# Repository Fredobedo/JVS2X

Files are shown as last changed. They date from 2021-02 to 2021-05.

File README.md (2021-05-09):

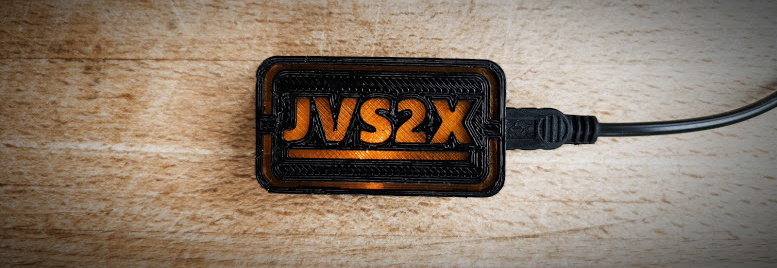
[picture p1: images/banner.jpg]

 <h2>Introduction </h2>
 I was not really in favor of integrating Gaming consoles in arcade CABs but I gave a try with a Sony Playstation 3 and could confirm that:
 <BR>&nbsp&nbsp&nbsp-&nbspIt can natively output 640x480@60Hz with 4:3 aspect ratio (not all games)
 <BR>&nbsp&nbsp&nbsp-&nbspIt natively supports Logitech G25 racing Wheel with full FFB and has some excellent arcade ports (i.e. OutRun 2 SP, Sega Rally, GTI Club)
 <BR>&nbsp&nbsp&nbsp-&nbspIt can run arcade Shoot'em ups (i.e. RayStorm HD) and Beat'em ups (i.e. Street Fighter IV Arcade Edition)
 <BR>&nbsp&nbsp&nbsp-&nbspIt could be an excellent solution for rail shooting games with also very interesting arcade ports
 <BR>
 <BR>For the racing games, it was not a problem as I could directly connect my racing wheel but I needed an interface for being able to play other games with my CAB's controller. 
 <BR> -> I decided to use a Teensy 2.0 for this purpose as already done by other users but with small changes to fit my needs. 
 <BR> 
 <BR>JVS2X (Teensy) acts as an interface between the Game console/PC and the Arcade JVS IO Board, converting JVS protocol to USB (software HID Device). 
 <BR>When compiled in JVS2PS3 mode, the Teensy will represents a USB composite Device exposes 2 HID interfaces of type gamepad controllers.
 <BR>When compiled in JVS2KEYBOARD mode, the Teensy will represents a USB composite Device exposes 2 HID interfaces of type Keyboard. 
 <BR>
 <BR>Here is a non exhaustive list of systems that should be compatible today when compiled in JVS2PS3 mode (TBC):
 <BR>&nbsp&nbsp&nbsp-&nbspSony Playstation 3 (Home button supported: 'Start + Button 1')
 <BR>&nbsp&nbsp&nbsp-&nbspMicrosoft Windows (i.e. Mame)
 <BR>&nbsp&nbsp&nbsp-&nbspLinux based systems (i.e. RetroPie)
 <BR>&nbsp&nbsp&nbsp-&nbspNintendo Switch 
 <BR>&nbsp&nbsp&nbsp-&nbspEtc.
 <BR>
 <BR>This project is not something new; it is highly inspired from other projects referenced at the bottom of this page.
 <BR>Do not hesitate to look at these projects to have more information.
 <BR>
 <BR>What could be considered as new here, is the way it is implemented (technical aspects):
 <BR>&nbsp&nbsp&nbsp-&nbspBulk JVS Commands dynamically built based on supported JVS client features
 <BR>&nbsp&nbsp&nbsp-&nbspAnalog and LightGun support
 <BR>&nbsp&nbsp&nbsp-&nbspDaisy chain support
 <BR>&nbsp&nbsp&nbsp-&nbspConfigurable multi CABs
 <BR>&nbsp&nbsp&nbsp-&nbspOptimized USB report updates
 <BR>&nbsp&nbsp&nbsp-&nbspBasic Analog Fuzz filters
 <BR>&nbsp&nbsp&nbsp-&nbspController remapping facilities
 <BR>&nbsp&nbsp&nbsp-&nbsp2 keyboards interfaces to circumvent limitation of 8 keystrokes (6 non-modifier keycodes + 2 modifiers) per Keyboard report (=> 2x 6KRO).
 <BR>&nbsp&nbsp&nbsp-&nbspSupport multi Keyboard layout
 <BR>&nbsp&nbsp&nbsp-&nbspSupport for programmable shiftKeys
 <BR>&nbsp&nbsp&nbsp-&nbspEtc. 
 <BR> 
 <BR>Here is a video of a PS3 in an arcade CAB with Logitech G25 Racing Wheel (FFB full support natively) :
 <BR><a href="http://www.youtube.com/watch?feature=player_embedded&v=FEGdqCKUjls
" target="_blank">IMAGE ALT TEXT HERE</a>
  
 <BR>Here is another video of a PS3 in an arcade CAB but this time with a JVS2X adapter connected to JVS IO Board (for 'sticks' games) :
 <BR><a href="http://www.youtube.com/watch?feature=player_embedded&v=nGHq-c_uzvw
" target="_blank">IMAGE ALT TEXT HERE</a>
  
 <BR>
  
 <BR>TODO: Implement HID for PS4, XBOX One, etc. when I have time or with your help :) 
 
<h2>Supported arcade layout</h2>
JVS2X is developed to support device chaining, thus it supports multiple JVS IO boards in the same CAB or in different CABs (Clone mode, VS mode, etc.)
<BR>All is implemented but I can't test as I do only have 1 CAB :( 
<BR>If someone is willing to give it a try, I will be more than happy to help in case of trouble
<BR>
<BR>You can configure your CAB's layout by updating file jvs_host_config.h:
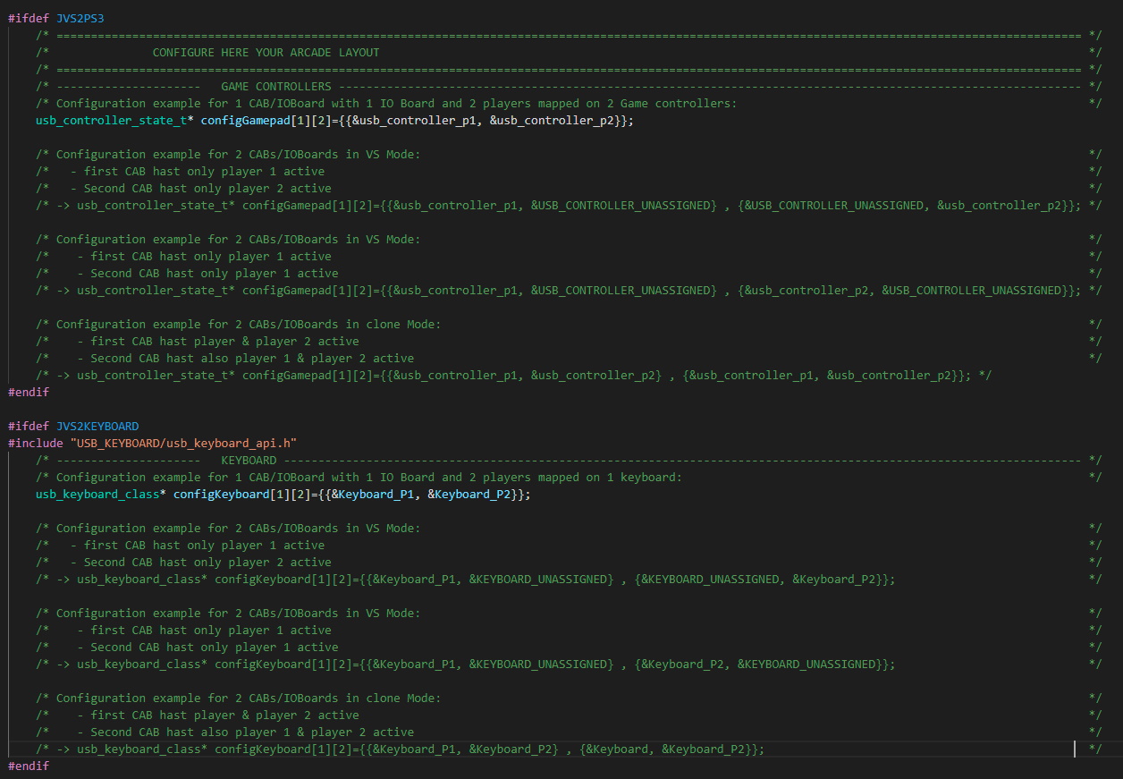
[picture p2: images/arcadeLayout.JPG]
<BR> 

<h2>Building the hardware</h2>
Here are the components you need to construct your adapter (total max. 15€):
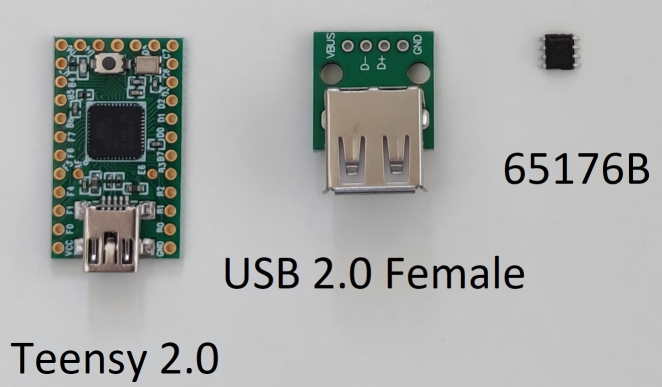
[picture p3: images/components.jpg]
   

<BR>Then, you have the possibility to buy a pcb helper for a very reasonable from Aganyte (easy way):
<table>
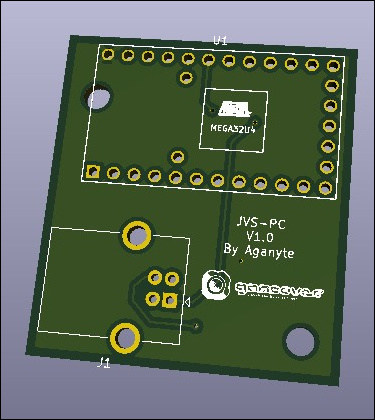
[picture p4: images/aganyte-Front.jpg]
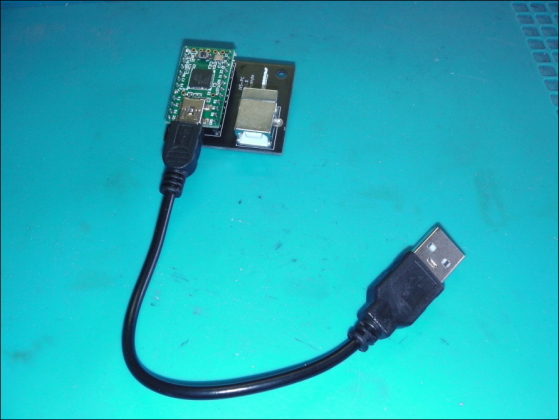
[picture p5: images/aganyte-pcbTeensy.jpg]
<td></td><td></td>
</table>
more information at https://www.gamoover.net/Forums/index.php?topic=43288.0

<BR>And for the courageous one, here is diagram for soldering all yourself without the Aganyte's PCB (hardcore way):
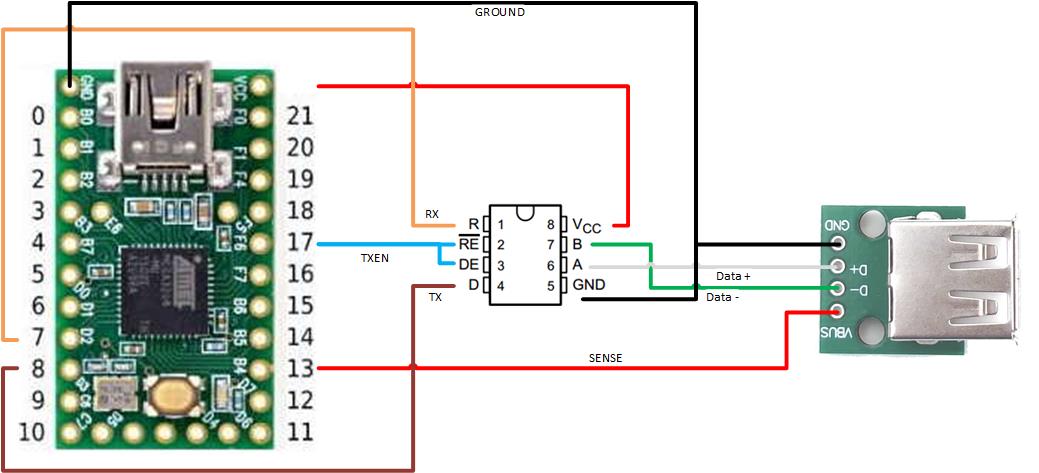
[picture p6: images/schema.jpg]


This is the way I soldered mine (c/o compatible enclosure below if needed):
<table>
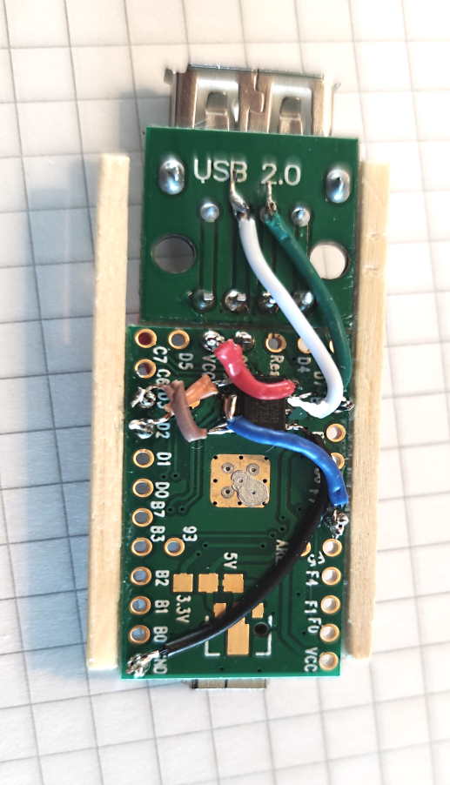
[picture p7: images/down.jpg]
<td></td>
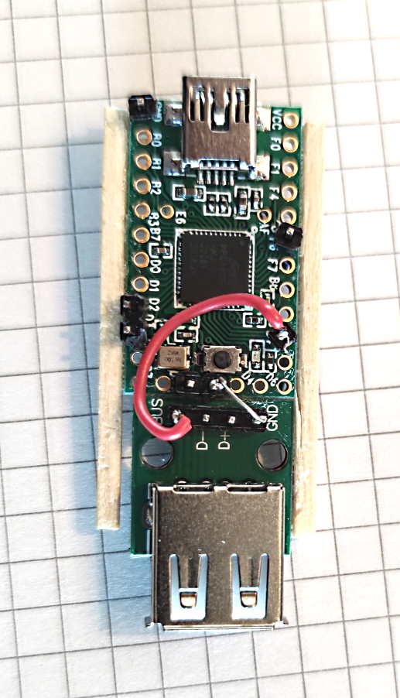
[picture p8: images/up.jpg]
<td></td>
</table>
There are also additional pictures from other realizations for other persons, in the doc folder if needed.

<h2>Printing an enclosure</h2>
I also designed a box for the JVS2X:
<table>
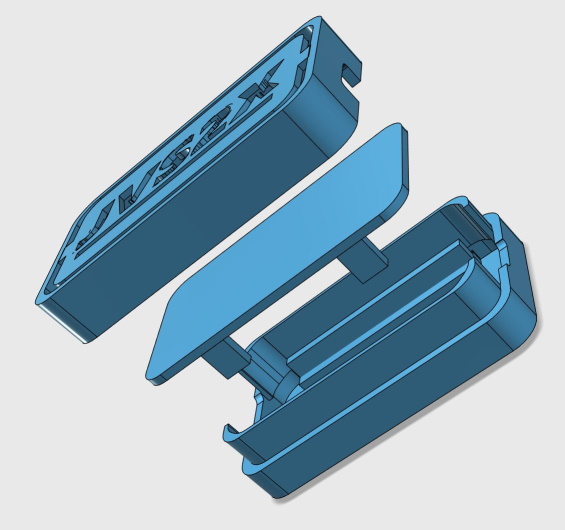
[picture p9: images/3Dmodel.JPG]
<tr><td colspan="2"></td></tr>
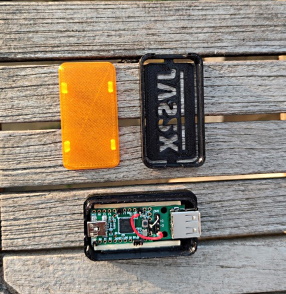
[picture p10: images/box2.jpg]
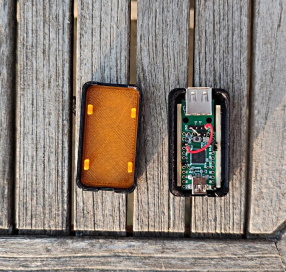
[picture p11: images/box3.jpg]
<tr><td></td><td></td></tr>
</table>
In case you are interested, You can find the 3 STL files in the 'Enclosure' folder.

<h2>Compiling the software</h2>
 For now on, I use VS Code with PlatformIO IDE extension:
 <BR>&nbsp&nbsp&nbsp-&nbspBoard: Teensy 2.0
 <BR>&nbsp&nbsp&nbsp-&nbspFramework: Arduino
 <BR>Here are the supported build flags (c/o platformio.ini):
  <table>
 <TD>&nbsp&nbsp&nbsp-&nbspJVS2PS3</td><td> -> create 2 gamepad controllers compatible with ps3, pc, etc.</td><tr>
 <TD>&nbsp&nbsp&nbsp-&nbspJVS2KEYBOARD</td><td> -> create 2 keyboards</td><tr>
 <TD>&nbsp&nbsp&nbsp-&nbspJVSDEBUG=1</td><td> -> activate info traces</td><tr>
 <TD>&nbsp&nbsp&nbsp-&nbspJVSDEBUG=2</td><td> -> activate debug traces</td><tr>
 <TD>&nbsp&nbsp&nbsp-&nbspLAYOUT_FRENCH_BELGIAN</td><td> -> set keyboard layout to French for Unicode keyboard mapping</td><tr>
 <TD>&nbsp&nbsp&nbsp-&nbspSENSE_DISABLED</td><td> -> disable sense line</td><tr>
 <TD>&nbsp&nbsp&nbsp-&nbspSHIFTKEY_DISABLED</td><td> -> disable keyboard shift keys support</td><tr>
  </table>
 <BR>If you don't want to compile it, there is already a compiled version in 'build' folder
  
 <h2>Upload software</h2>
 Please upload 'jvs2x.hex' in your Teensy with help of Teensy Loader (c/o pjrc.com).
 <BR>
 
 <h2>Debugging</h2>
You can compile JVS2X with JVSDEBUG flag; this will create a additional HID interface that you will connect with help of hid_listen.exe (c/o https://www.pjrc.com/teensy/hid_listen.html for more information)
<BR>
<BR>You should see these traces:
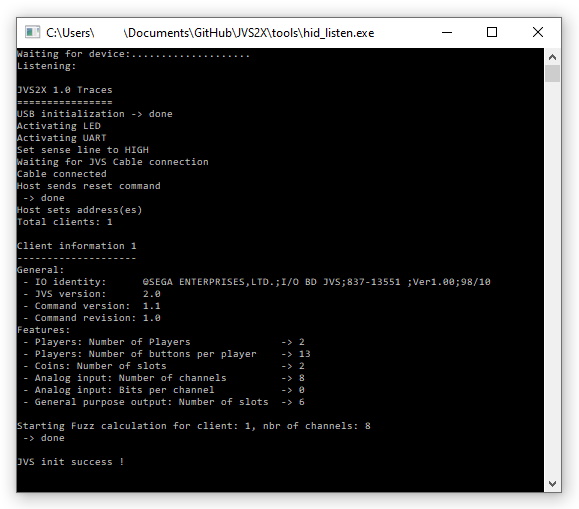
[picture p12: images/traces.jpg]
<BR>
<BR>If you do not want to compile it, I also have placed debug versions in 'build' folder too.

 <h2>LED States</h2>
JVS2X uses the Teensy internal LED to indicate several states:
<BR>&nbsp&nbsp&nbsp-&nbspContinuously blinking: waiting for a JVS cable to be connected
<BR>&nbsp&nbsp&nbsp-&nbspNo blink: init phase started
<BR>&nbsp&nbsp&nbsp-&nbspSteady ON: JVS init is finished successfully and the device is ready

<h2>Compatibilty list</h2>
Here are some games confirmed to work on Sony PlayStation 3:
<BR>&nbsp&nbspWorking:
<BR>&nbsp&nbsp&nbsp-&nbspUnder defeat HD
<BR>&nbsp&nbsp&nbsp-&nbspRayStorm HD
<BR>&nbsp&nbsp&nbsp-&nbspSuper Street Fighter IV Arcade Edition
<BR>&nbsp&nbsp&nbsp-&nbspVirtua Fighter 5 
<BR>&nbsp&nbsp&nbsp-&nbspSöldner-X 2
<BR>&nbsp&nbsp&nbsp-&nbspSuper Street Fighter ii Turbo HD Remix
<BR>&nbsp&nbsp&nbsp-&nbspR-Type Dimensions
<BR>&nbsp&nbsp&nbsp-&nbspMetal Slug 2 
<BR>&nbsp&nbsp&nbsp-&nbspCapcom Arcade Cabinet (Ghodtd'n goblins, Commando, Gun Smoke, section7, etc.)
<BR>&nbsp&nbsp&nbsp-&nbspSky force Anniversary
<BR>&nbsp&nbsp&nbsp-&nbspAfter burner 
<BR>&nbsp&nbsp&nbsp-&nbspSonic generations 
<BR>&nbsp&nbsp&nbsp-&nbspWipeOut HD Fury
<BR>
<h2>Controller mapping</h2>
Some PS3 buttons do not exist on a arcade control panel. These are mapped as follow:
<BR>&nbsp&nbsp&nbsp-&nbspSTART + Button 1 -> PS Button
<BR>&nbsp&nbsp&nbsp-&nbspSTART + Button 2 -> Select
<BR>
<BR> You can reconfigure the default control mapping to your likings by updating the file jvs_controller_ps3_config.h:
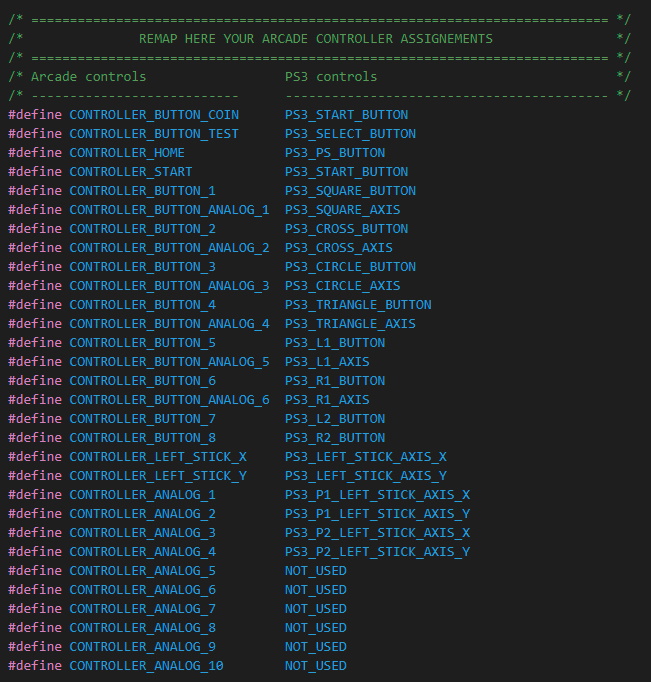
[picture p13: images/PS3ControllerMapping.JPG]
<BR>

<h2>Keyboard mapping</h2>
Keyboard mapping is done by updating the file jvs_keyboard_config.h
<BR>Keyboard mapping can be done by giving keycodes or unicodes.
<BR>It is strongly advised that you use keycode mapping for your emulators (i.e. Mame).
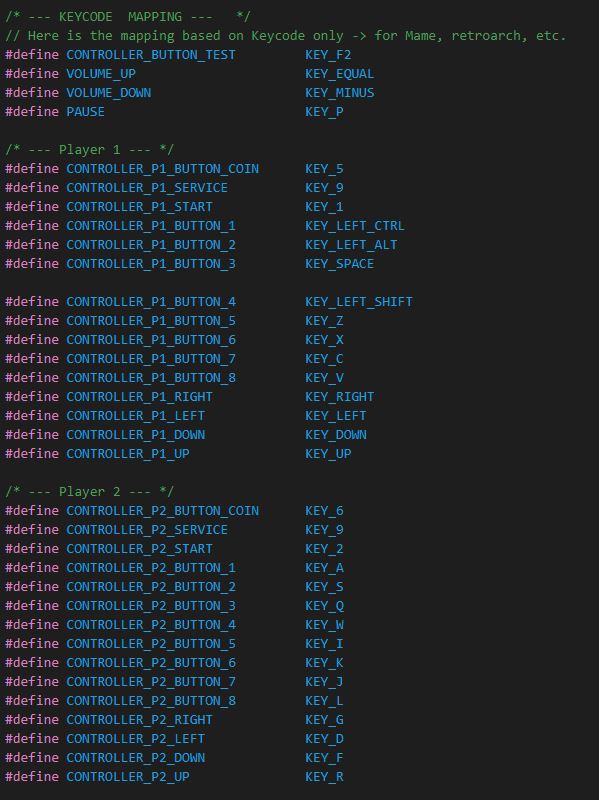
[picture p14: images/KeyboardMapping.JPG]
<BR>
<BR>
 <BR>If for any reason you would still like to use unicode caracters, it is possible but you will have to select also the according keyboard layout (default is 'US'):
<BR><BR>The desired keyboard layout (i.e. "LAYOUT_FRENCH") must be given at compile time as parameter (c/o platformio.ini) 
<BR>For now it supports those layouts (extract from keylayouts.h):
<TABLE> 
<TR><TD>&nbsp&nbsp- LAYOUT_US_ENGLISH          </TD><TD>&nbsp&nbsp- LAYOUT_US_INTERNATIONAL</TR>
<TR><TD>&nbsp&nbsp- LAYOUT_GERMAN              </TD><TD>&nbsp&nbsp- LAYOUT_GERMAN_MAC</TR>
<TR><TD>&nbsp&nbsp- LAYOUT_CANADIAN_FRENCH     </TD><TD>&nbsp&nbsp- LAYOUT_CANADIAN_MULTILINGUAL</TR>
<TR><TD>&nbsp&nbsp- LAYOUT_UNITED_KINGDOM      </TD><TD>&nbsp&nbsp- LAYOUT_FINNISH</TR>
<TR><TD>&nbsp&nbsp- LAYOUT_FRENCH              </TD><TD>&nbsp&nbsp- LAYOUT_DANISH</TR>
<TR><TD>&nbsp&nbsp- LAYOUT_NORWEGIAN           </TD><TD>&nbsp&nbsp- LAYOUT_SWEDISH</TR>
<TR><TD>&nbsp&nbsp- LAYOUT_SPANISH             </TD><TD>&nbsp&nbsp- LAYOUT_PORTUGUESE</TR>
<TR><TD>&nbsp&nbsp- LAYOUT_ITALIAN             </TD><TD>&nbsp&nbsp- LAYOUT_PORTUGUESE_BRAZILIAN</TR>
<TR><TD>&nbsp&nbsp- LAYOUT_FRENCH_BELGIAN      </TD><TD>&nbsp&nbsp- LAYOUT_GERMAN_SWISS</TR>
<TR><TD>&nbsp&nbsp- LAYOUT_FRENCH_SWISS        </TD><TD>&nbsp&nbsp- LAYOUT_SPANISH_LATIN_AMERICA</TR>
<TR><TD>&nbsp&nbsp- LAYOUT_IRISH               </TD><TD>&nbsp&nbsp- LAYOUT_ICELANDIC</TR>
<TR><TD>&nbsp&nbsp- LAYOUT_TURKISH             </TD><TD>&nbsp&nbsp- LAYOUT_CZECH</TR>
<TR><TD>&nbsp&nbsp- LAYOUT_SERBIAN_LATIN_ONLY  </TD><TD></TR>
<table>
<BR>Here is an example of Keyboard mapping with unicode caracters:
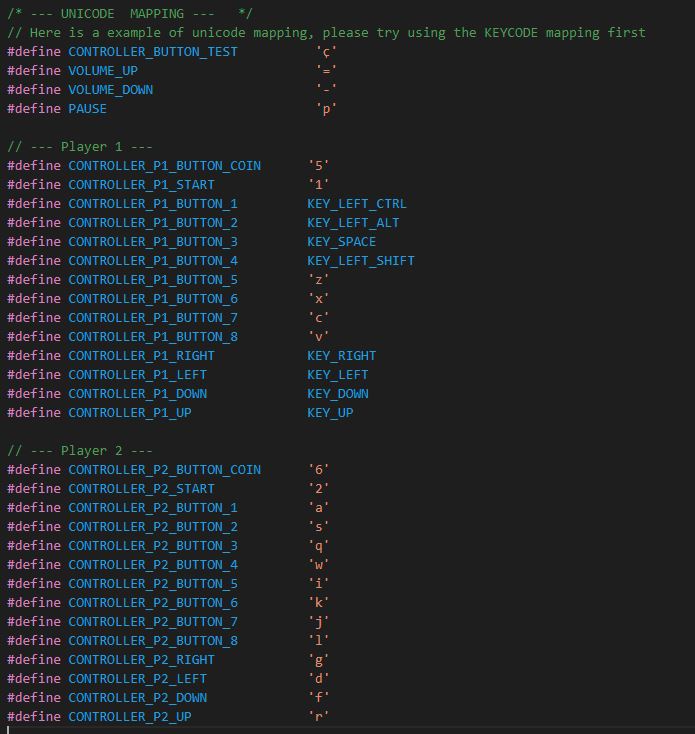
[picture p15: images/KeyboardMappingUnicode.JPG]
<BR> 
<BR>Please note that you can also define 'Shift Keys' in this same Keyboard configuration file:
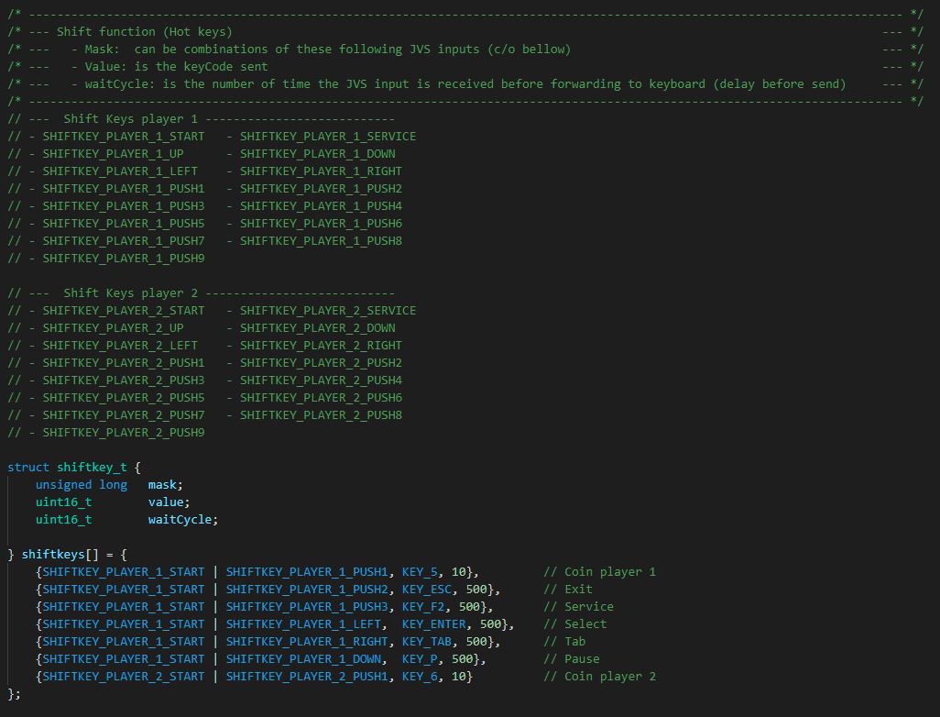
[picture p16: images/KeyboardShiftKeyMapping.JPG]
<BR> 
 
<h2>Fault tolerance</h2>
There is no special order to follow when starting your JVS2X, all orders are supported.
<BR> 
<BR>JVS2X will detect these follow errors and act upon:
 <table>
  <tr><td>&nbsp&nbsp&nbsp-&nbspJVS cable removed</td><td>-> JVS2X will wait for JVS cable and reinitialize when detected.</td></tr>
  <tr><td>&nbsp&nbsp&nbsp-&nbspJVS IO Board powered off</td><td>-> JVS2X will wait for JVS IO Board powered on again and reinitialize when detected.</td></tr>
  <tr><td>&nbsp&nbsp&nbsp-&nbspPS3 Powered off and on again</td><td>-> JVS2X is also powered off and on as it is powered by the PS3 USB.</td></tr>
  </table>
<BR>If for any reason, you have the impression that JVS2X is blocked or not responding accordingly, you can always try to restart it by pressing these 3 buttons at the same time: START + Button 1 + Button 2 -> Restart JVS2X
<h2>Sony PlayStation 3 video output</h2>
 In my journey to integrate the Sony PS3 in my CAB, I spent several weeks finding the best way to connect the video output.
 <BR>Let me share my experience and my final implementation.
 <h3>640x480@60Hz</h3>
 The PS3 can output this resolution ONLY if the region is set to NTSC:
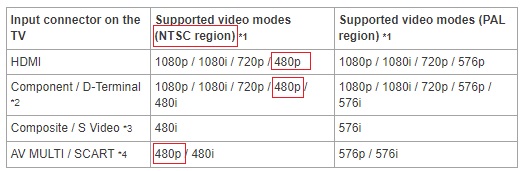
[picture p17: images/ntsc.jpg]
 <BR>
 (extract from https://manuals.playstation.net/document/en/ps3/3_15/settings/videooutput.html)
 <BR>
 <BR> -> So you have 2 choices, either you have a NTSC PS3 or you you have a PAL PS3 that you can change region with help of CFW and some registry updates.
 <h3>"VGA" cable</h3>
 Next, I had to look at the video connectivity and first tried one of those PS3 to VGA cable:
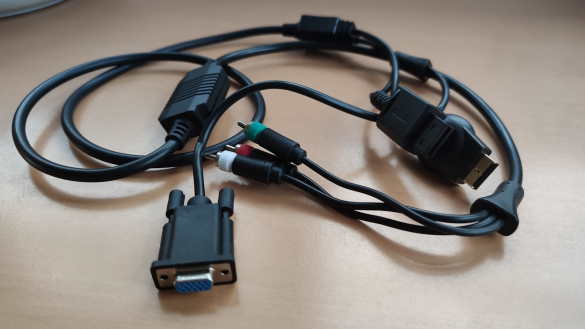
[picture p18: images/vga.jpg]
 <BR> 
 <BR>This was a mistake, the image was very dark, washed and colorimetry was wrong. It turned out that this was not a standard VGA output (RGB HV) but D-Terminal (Sync on Green, D2). This video format can also be found on Sony PS2 and Nintendo GameCube.  More info at https://en.m.wikipedia.org/wiki/D-Terminal.

<h3>Component out</h3>  
Then I tried the component Video out cable that I connected to my GBS Control (custom CBS 8200) configured to direct output to same resolution in VGA and surprise, it worked well!
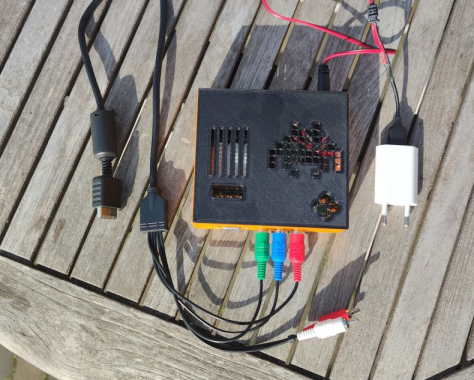
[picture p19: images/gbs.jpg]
<BR> 
Looking at it a bit more after some days, it was kind of working but the image was a little too blury and it was a bit overkill, no? So I decided to look at something else.

 <h3>HDMI + DAC</h3>
 I decided to give a try to this little DAC converter, after all that is what we can also find on Video cards with VGA output:
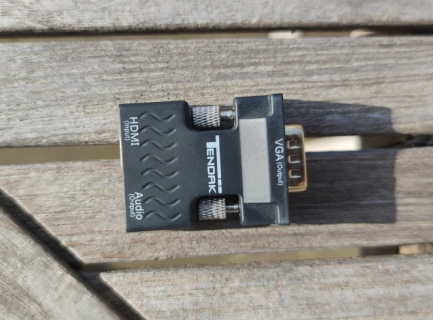
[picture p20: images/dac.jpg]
 <BR>  
 The result is just perfect! Image is sharp, without any lags or screen tearing, simple to use and so cheap!?! 
 <BR> -> That is my solution.
 <BR> 
 <BR>Please note that this little adapter does not downscale, etc. It is just a DAC converter. So the HDMI out on PS3 is configured to output 480p.

<h2>External references</h2>
 This project is based on:
 <BR>&nbsp&nbsp&nbsp-&nbspJVSy from k4roshi (https://github.com/k4roshi/JVSy)., 
 <BR>&nbsp&nbsp&nbsp-&nbspAdapted version of JVSy (https://github.com/gtranche/JVSy).
 <BR>&nbsp&nbsp&nbsp-&nbspOpenJVS (https://github.com/OpenJVS/OpenJVS).
 <BR>
 <BR> Many thanks for sharing all these precious sources of information and also a special thanks to Bobby & Francesco for all thier help, ideas and support!
  <BR>
  <BR>Have fun & best regards.
  <BR>Fred

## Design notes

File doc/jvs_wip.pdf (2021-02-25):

# DRAFT

# JAMMA Video Standard (JVS) Third Edition

Designed by JAMMA
Translated/edited/etc. by Alex Marshall

August 14, 2019

c 2015-2019 Alex ”trap15” Marshall, All rights reserved.

1

# DRAFT

JAMMA VIDEO STANDARD

c 2015-2019 Alex ”trap15” Marshall, All rights reserved

## Contents

1 Introduction | 4
2 Physical Layer | 6
3 Link Layer | 7
4 Command Format | 9

# DRAFT

| 4.3.39 Command: NAMCO Extended ID? (NAMCOEXTID) | | 23
| 4.3.40 Command: NAMCO Extended Cmd 03h (NAMCOEXT03) | | 23
| 4.3.41 Command: NAMCO Extended Cmd 04h (NAMCOEXT04) | | 23
| 4.3.42 Command: NAMCO Extended Cmd 22h (NAMCOEXT22) | | 23
| 4.3.43 Command: CyberLead LED NOP (CYBERLEDNOP) | | 23
| 4.3.44 Command: CyberLead LED Set Scene (CYBERLEDSCENE) | | 24
| 4.3.45 Command: CyberLead LED Data Check (CYBERLEDCHECK) | | 24
| 4.3.46 Command: CyberLead LED Cmd 04h (CYBERLED04) | | 24
| 4.3.47 Command: CyberLead LED Data Upload (CYBERLEDUPLOAD) | | 24
| 4.3.48 Command: CyberLead LED Cmd 06h (CYBERLED06) | | 25
| 4.3.49 Command: CyberLead LED Upload End (CYBERLEDFINISH) | | 25

## List of Tables

1 | DC Power Input Requirements | | 4
2 | Maximum size of main PCB | | 5
3 | Physical Layer Pin-out | | 6
4 | Physical Layer Attributes | | 6
5 | Command Listing | | 9
6 | Status Code Listing | | 11
7 | Report Code Listing | | 11
8 | Function Code Listing | | 14
9 | Character Output Type Listing | | 14
10 | Switch Input Data Format | | 15
11 | Switch Input Data Format (2 Joysticks) | | 15
12 | Switch Input Data Format (Mahjong Panel) | | 16
13 | Coin Input Data Format | | 16
14 | Coin Condition Code List | | 16
15 | 10-bit Analog Input Data Format | | 17
16 | Coin Condition Code List | | 18
17 | 10-bit Analog Output Data Format | | 20
18 | Character Output Control Codes | | 20
19 | Data Bank Restrictions | | 25

# DRAFT

## 1 Introduction

1. Scope of application: This standard defines the main board used for general video game machines, which satisfies the technical requirements of the Electrical Appliance and Material Control Law, and the Electrical Appliance and Material Safety Law.
2. Terminology used: The meaning of the terms used in this standard is as follows.
2.1 General Video Game Machine: A coin operated game machine using a CRT monitor.
2.2 Main PCB: The central board used to drive the game machine.
2.3 Video Output: The outputs from the main PCB to the CRT, consisting of the RGB, and sync signals.
2.4 Sync Output: A composite signal with no color data.
2.5 RGB Output: Individual color signals, with no sync data.
2.6 Video Signal Timing Chart: Shows the change of sync and color signals over time for each vertical and horizontal scan.
2.7 Raster: One scanline’s worth of video output.
2.8 DC Power Input: Various DC power supply inputs supplied to the main PCB.
2.9 Audio Output: Analog audio output from the main PCB.
2.10 I/O Board: Connects by serial to the main PCB, controls switch inputs, volume, coin counters, lamps, etc.
2.11 Connectors: Various connectors used when electrically connecting main PCB and external pe-ripheral device.
2.12 JAMMA Mark: Abbreviation logo trademarked by Japan Amusement Machine Industry Asso-ciation.
3. Video Output
3.1 Video Output: Video can be output to two monitors.
3.2 Horizontal Scan Frequency: The horizontal scan frequence shall be 15.750kHz, 24.830kHz, or 31.500kHz.
3.3 RGB Output
3.3.1 Levels: RGB output levels shall be 0.7Vp-p±10%.
3.3.2 Signaling: RGB output signals are AC coupled, with a 470µF capacitance. Connect to GND with a terminating resistor of 75Ω.
3.4 Sync Output
3.4.1 Levels: Sync output level shall be TTL levels, with high level voltage being 2.4V through 5.0V.
3.4.2 Signaling: Sync signals are DC coupled. Connect to GND with a terminating resistor of 470Ω.
3.4.3 Types: Sync output is either Composite only, or Separate. When composite, V-sync is not connected, or TTL low level.
3.5 TODO: Bring back once I add the graphs (see 3.4 in JVST VER3.pdf if you really care, it’s just referring to a chart of video signals).
4. DC Power Input
4.1 Types: DC power inputs should be +5V0, +3V3, and +12V0-.
4.2 Margins: Voltage error, current capacity, ripple, and minimum load current of each DC power input are shown in the below table.

Table 1: DC Power Input Requirements
Power Input | Error | Current Capacity | Ripple | Minimum Load Current
+5V0 | ±5% | Up to 10A | Up to 80mV p-p | 0A
+3V3 | ±5% | Up to 12A | Up to 80mV p-p | 0A
+12V0 | ±10% | Up to 2A | Up to 120mV p-p | 0A

4.3 Power On Sequence: The +3V3 rail must come up completely before +5V0. The time between +3V3 reaching 90% and +5V0 reaching 10% must be greater than or equal to 1 millisecond. The time between +3V3 reaching 90% and +5V0 reaching 90% must be between 1 and 1000 milliseconds. All power terminals must be connected, there must be no potential difference between each terminal.
4.4 Power Off Sequence: The +5V0 rail must turn off completely before +3V3. The time between +5V0 reaching 90% and +3V3 reaching 90% must be between 1 and 1000 milliseconds.
4.5 TODO: Add the nice diagrams for these

# DRAFT

5. Audio Output
5.1 Levels: Audio output level is 0±6 dB (0V5-2V0 rms, or 1V41-5V66 p-p), with output impedance of 2kΩ or less.
5.2 Output Channels
5.2.1 Stereo output: Audio output should use two channels.
5.2.2 Extended output: Audio expansion output can use up to two channels.
5.2.3 Mono output: Audio output should be the same as stereo output, just with the same data. 5.3 Volume Adjustment: Volume adjustment is done on the cabinet itself, not on the main PCB.
6. Standard I/O
6.1 Standard I/O: The I/O refers to the unit which communicates with the main PCB, and controls reading of switches, levers, coins, volume, etc, and controls coin counters, lamp drivers, etc. 6.1.1 Signal types: The I/O is connected using a serial connection conforming to EIA-RS485 standard (half duplex).
6.1.2 Communication Setup
A. Read from the I/O board: the manufacturer, product number, version, etc.
B. Allocate addresses for each node in sequence.
C. In the future, when version upgrade of the basic part such as communication speed is done, confirm the correspondence by confirm command and switch all nodes to new version by setting command. (TODO: retranslate)
6.1.3 Coin Count Management
A. The I/O board manages the number of coins, and number of pay-outs. It may save this data in case of power loss.
B. The I/O board notifies the main PCB of the number of available coins (or remaining credit for a card system). The main PCB sends information such as number of coins to consume when a game is started.
C. The I/O board additionally manages number of pay-outs, such as medal hoppers, and the main PCB only conveys the amount won.
6.1.4 Command Format: Command format is specified later.
7. Connectors
7.1 Connector types: The connector types are unique for each connector’s functionality (DC power supply, video output, audio output, standard I/O input, standard I/O output).
7.2 TODO: The rest of this section (mostly not important, requires diagrams)
8. Main PCB Dimensions

Table 2: Maximum size of main PCB
Dimension | mm | in
Width | 390mm | 15.3”
Height | 450mm | 17.7”
Depth | 150mm | 5.9”
9. TODO: items 9 10 and 11 omitted for irrelevance TODO: Really nice diagrams

# DRAFT

## 2 Physical Layer

The JVS I/O physical layer uses RS-485 standard for serial transmission. The physical connection uses USB-A and USB-B connectors. The protocol is half-duplex multi-point, so all DATA lines are shared. The Sense line is point-to-point between adjacent nodes, and pull-down. Each device which supports daisy-chaining will have two JVS I/O ports, with the outgoing port being a USB-A connector, and the incoming port being a USB-B connector. The master node will thus only have a USB-A connector, and a slave node without daisy chaining will only have a USB-B connector.

Table 3: Physical Layer Pin-out
USB Pin | USB Color | JVS Signal | RS-485 Signal
1 | Red | Sense | N/A
2 | White | DATA- | A
3 | Green | DATA+ | B
4 | Black | GND | GND

Table 4: Physical Layer Attributes
Attribute | Value
Baud Rate | 115200
Data Bits | 8
Parity | None
Stop Bits | 1

# DRAFT

## 3 Link Layer

### 3.1 Framing

### 3.1.1 SYNC and MARK

All frames start with a SYNC byte (0xE0). When any SYNC byte is encountered, a new packet begins. To allow using the SYNC byte in the payload, there is a MARK byte (0xD0) which increments the following byte by one. Thus, a real byte of 0xE0 is encoded as 0xD0 0xDF, and a real byte of 0xD0 is encoded as 0xD0 0xCF. The MARK processing is transparent, and as such the rest of the protocol is completely ignorant to its existence. All processing should occur on raw data before MARK addition or after MARK removal.

3.1.2 Node No.

All frames include the destination node number. If the node number is 0xFF, that indicates that the packet is Broadcast, and thus meant for all nodes. Node 0x00 is fixed to be the master node, and nodes 0x01 through 0x1F are for slave nodes, to be assigned at initialization. Each device should only process packets designated for it.

### 3.1.3 Byte Count

This field contains the number of bytes left in the packet, including the SUM byte.

### 3.1.4 SUM

All bytes in the packet aside from SYNC and SUM are added together, modulo 256. If this value and SUM do not match, the packet is corrupt.

### 3.2 Request/Acknowledge Scheme

### 3.2.1 Requests

The master is the only node allowed to initiate communication, to prevent cases where multiple devices try to talk at once and blow each other up. To improve performance, multiple commands may be combined into a single packet simply by concatenating them. The acknowledge packet must include responses to all of the commands in the packet.
Listings of the Command codes can be found in Section 4.1.

### 3.2.2 Acknowledges

Every request (except for most broadcast packets) require an acknowledge packet in response which includes any return values requested. Each acknowledge packet starts with a Status code, which provides information on what the slave node thinks about the incoming packet. For each command in the request packet, there is one Report code which provides information on what the slave node thinks about that specific command. Actual response data follows the Report code.
Listings of the Status and Report codes can be found in Section 4.2.

### 3.3 Initialization

For initialization, the master should send a Reset packet twice to reset all slave nodes to their uninitialized state. This will cause them to set their sense lines high, and to forget their node number.
Following, the master will send Set Address packets with increasing address values. This command is the only broadcast command that has a response, which acknowledges that a node received the command.

# DRAFT

When a node receives this packet, it should ignore it unless its incoming sense line is low. This makes the farthest node receive address 0x01, and the closest to receive the last node. When a node has its address set, it should pull sense low.
Master should stop sending packets once its incoming sense goes low, as this means all nodes have addresses.

# DRAFT

## 4 Command Format

Exchange of data between the main board and the I/O board is performed by a command sent by the master (main board). Since the slaves are unable to send a request to the master, the master must periodically check the slaves for data.
The overhead for transmitting a single packet at a time is relatively large, so typically many packets are sent at once for more efficient data exchange. When a slave receives multiple packets at once, it must process them in order and reply in the order received. If the data takes a long time to process, busy is returned during processing.

### 4.1 Command Codes

Table 5: Command Listing

Req. | Name | Code | Description | Request Size

Response
Size

GLOBAL COMMANDS (NODE NO.FF)

Reset | F0 | Reset communication status of all slaves | 2 | 0
Set Address | F1 | Set the slave address | 2 | 1
Comm. Method Change | F2 | Request to change communication speed? | 2 | 0

INITIALIZE COMMANDS

I/O Identify | 10 | Get slave ID data | 1 | MAX 102
Command Revision | 11 | Command format revision | 1 | 2
JVS Revision | 12 | JVS revision | 1 | 2
Comm. Version | 13 | Communications version | 1 | 2
Feature Check | 14 | Check slave features | 1 | 6+
Main ID | 15 | Send ID of main board | MAX 102 | 1

DATA I/O COMMANDS

Switch Inputs | 20 | Read controller switches | 3 | 3+
Coin Inputs | 21 | Read coin counters | 2 | 2 × slots
Analog Inputs | 22 | Read analog inputs | 2 | 2 × ports
Rotary Inputs | 23 | Read rotary inputs | 2 | 2 × ports
Keycode Inputs | 24 | Read keycodes? | 1 | 2
Screen Position Inputs | 25 | Read touch-panel/gun inputs | 2 | 5
Misc. Switch Inputs | 26 | Read miscellaneous switch inputs | 2 | 2+

OUTPUT COMMANDS
Remaining Payout | 2E | Read information such as remaining number of medals in hopper? | 2 | 5
Data Retransmit | 2F | Checksum error, request a retransmission | 1 | 0
Coin Counter Decrease | 30 | Decrement the coin counter | 4 | 1
Payout Counter Increase | 31 | Increment the payout counter | 4 | 1
Generic Output 1 | 32 | Data output to the parallel driver | 3+ | 1

# DRAFT

Analog Output | 33 | Data output to analog output unit | 4+ | 1
Character Output | 34 | ASCII code output to 7seg LED or LCD | 3+ | 1
Coin Counter Increase | 35 | Increment the coin counter | 4 | 1
Payout Counter Decrease | 36 | Decrement the payout counter | 4 | 1
Generic Output 2 | 37 | Byte data output to the parallel driver? | 3 | 1
Generic Output 3 | 38 | Bit data output to the parallel driver? | 3 | 1

MANUFACTURER-SPECIFIC COMMANDS
60
7F
TAITO TYPEX COMMANDS (NODE NO.00)
Machine Reset | 00 | Reset the machine | 1 | 1
DIP Switches | 01 | Get TypeX board DIP switches | 2 | 2
Unknown 02 | 02 | Unknown | ? | 2
Unknown 03 | 03 | Unknown | ? | 1
Watchdog? 04 | 04 | Unknown? Watchdog related | 1 | 1
Watchdog Set | 05 | Set watchdog timer expiration time | 3 | 1
Unknown 06 | 06 | Unknown | ? | 2
Unknown 07 | 07 | Unknown | ? | 1
Watchdog Kick | 08 | Watchdog kick | 1 | 2

# DRAFT

### 4.2 Status and Report Codes

Status is sent with each response to a request packet, to convey the current status to the master. Report is sent with each response to a single request command to tell the results of the command to the master. When a slave receives a command that it does not support, all subsequent packets are discarded, and returns the Unknown command status. Also, if the command that was executed it previously, report the acknowledge packet (if there is a parameter that also) I return.

Table 6: Status Code Listing
Code | Description
01 | Normal
02 | Unknown command (Unsupported command)
03 | Checksum error
04 | Acknowledge overflow (Acknowledge data is too large)

Table 7: Report Code Listing
Code | Description
01 | Normal
02 | Parameter error (parameter is invalid). An incorrect number of parameters were sent.
03 | Parameter error (parameter is invalid). The data supplied was invalid.
04 | Busy. The I/O board cannot receive more commands until this command is complete.

# DRAFT

### 4.3 Detailed Command Description

### 4.3.1 Command: Reset (RESET)

Command name | Request Data | Response Data
Reset | F0, D9 | –
byte0 | F0 | Command Code | –
byte1 | D9 | Command Code | –

Resets the communication status of all slaves. Reset is a critical command, so there are two bytes to help ensure that the command is not issued mistakenly. Further, since reliability is paramount, it is recommended that this command be issued twice.
Initialization of the non-communication functions of the I/O board is not defined.

### 4.3.2 Command: Set Address (SETADDR)

Command name | Request Data | Response Data
Set Address | F1, address | 01 (report)
byte0 | F1 | Command Code | (01) | Report
byte1 | (01) | Address | –

Performs automatic setting of slave addresses. Only one slave will receive this command, and which receives it depends on the state of the sense lines. For slaves, address should start at 01 and increase in order. The master is always located at address 00, and broadcast is always at address FF. If an error is detected on the slave’s side, a pre-determined error report is returned.

### 4.3.3 Command: Comm. Method Change (COMMCHG)

Command name | Request Data | Response Data
Comm. Method Change | F2, method code | –
byte0 | F2 | Command Code | –
byte1 | (01) | Method Code | –

Changes the master and slave communication methods, such as to increase communication speed. This is a broadcast packet, so it is necessary to check that all I/O units are capable of the command sent. Whether this is supported can be determined by reading each I/O unit’s JVS Revision.

### 4.3.4 Command: I/O Identify (IOIDENT)

Command name | Request Data | Response Data
I/O Identify | 10 | 01 (report), ”ID CODE...”,00
byte0 | 10 | Command Code | (01) | Report
byte1 | – | | 4E | N’s ASCII code
... | – | | ... | ...
byteN | – | | 00 | End code

ID code is no more than 100 characters in ASCII format. Contains this information, in order: Maker name, I/O board code, software version number, and details. A zero byte must follow the string to denote the ending. Each field is separated by semicolons. The contents of each field are not particularly specified. EXAMPLE: "NAMCO LTD.;I/O PCB-1000;ver1.0;for domestic only,no analog input"

### 4.3.5 Command: Command Revision (CMDREV)

Command name | Request Data | Response Data
Command Revision | 11 | 01 (report), revision
byte0 | 11 | Command Code | (01) | Report
byte1 | – | | (13) | Revision code

Reads the revision of the command format supported by the I/O board. The code is written in BCD, with the low 4 bits being the decimal value.
The current revision is REV1.3, so the value would be 13.

# DRAFT

### 4.3.6 Command: JVS Revision (JVSREV)

Command name | Request Data | Response Data
Command Revision | 12 | 01 (report), revision
byte0 | 12 | Command Code | (01) | Report
byte1 | – | | (30) | Revision code

Reads the revision of the JVS supported by the I/O board. The code is written in BCD, with the low 4 bits being the decimal value.
The current revision is REV3.0, so the value would be 30.

### 4.3.7 Command: Communications Version (COMMVER)

Command name | Request Data | Response Data
Comm. Version | 13 | 01 (report), version
byte0 | 13 | Command Code | (01) | Report
byte1 | – | | (10) | Version code

Reads the version of the communication system supported by the I/O board. The code is written in BCD, with the low 4 bits being the decimal value.
The current version is VER1.0, so the value would be 10.

### 4.3.8 Command: Feature Check (FEATCHK)

Command name | Request Data | Response Data
Feature Check | 14 | 01 (report), func code, ..., 00
byte0 | 14 | Command Code | (01) | Report
byte1 | – | | (01) | (Switch input func-tion)
byte2 | – | | (02) | (Switch input func-tion, parameter 1)
byte3 | – | | (08) | (Switch input func-tion, parameter 2)
byte4 | – | | (00) | (Switch input func-tion, parameter 3)
... | – | | ... | ... (Next function)
byteN | – | | 00 | End code

List the features supported by the I/O board. Each function (except for end code) is 4 bytes, consisting of one function code byte and 3 parameter bytes.

# DRAFT

Table 8: Function Code Listing
Function | Code | Prm.1 | Prm.2 | Prm.3 | Parameter description
End code | 00 | – | – | – | End function list
INPUT FUNCTIONS
Switch input | 01 | players | buttons | 0 | Number of players, and how many switches per player. For example, 1L6B + START + SERVICE is 12 switches.
Coin input | 02 | slots | 0 | 0 | Number of coin slots
Analog input | 03 | channels | bits | 0 | Number of analog channels, number of effective bits (0 for un-known)
Rotary input | 04 | channels | 0 | 0 | Number of rotary encoders
Keycode input | 05 | 0 | 0 | 0 | ?
Screen position input | 06 | Xbits | Ybits | channels | Number of effective bits for X and Y axis, number of channels
Misc. switch input | 07 | SW MSB | SW LSB | 0 | Number of extra switches (big endian across Prm.1 and Prm.2)

OUTPUT FUNCTIONS
Card system | 10 | slots | 0 | 0 | Number of card slots
Medal hopper | 11 | channels | 0 | 0 | Number of medal hoppers
General-purpose output | 12 | slots | 0 | 0 | Number of outputs
Analog output | 13 | channels | 0 | 0 | Number of analog output chan-nels
Character output | 14 | width | height | type | Output display resolution in characters, and character code type
Backup | 15 | 0 | 0 | 0 | Has backup data for data such as number of coins

Table 9: Character Output Type Listing
Code | Output Type
00 | Unknown
01 | ASCII (numeric)
02 | ASCII (alphanumeric)
03 | ASCII (alphanumeric, half-width katakana)
04 | ASCII (kanji support, SHIFT-JIS)

# DRAFT

### 4.3.9 Command: Main ID (MAINID)

Command name | Request Data | Response Data
Main ID | 15, ”ID CODE...”,00 | 01 (report)
byte0 | 15 | Command Code | (01) | Report
byte1 | 4E | N’s ASCII code | –
... | ... | ... | –
byteN | 00 | End code | –

Sends the Main PCB’s ID code to the I/O board. ID code is no more than 100 characters in ASCII format. Contains this information, in order: Maker name, game name, software version number, and details. A zero byte must follow the string to denote the ending. Each field is separated by semicolons. The contents of each field are not particularly specified.
EXAMPLE: "NAMCO LTD.;TEKKEN2;ver1.6; TEKKEN2 ver B"

### 4.3.10 Command: Switch Inputs (SWINP)

Command name | Request Data | Response Data
Switch Inputs | 20, players, bytes | 01 (report), data, ...
byte0 | 20 | Command Code | (01) | Report
byte1 | (02) | Player count | (00) | Test and other sys-tem data
byte2 | (02) | Data bytes | (02) | Player 1 switch data, first byte
... | – | | ... | ...
byteN | – | | (00) | Last player switch data, last byte

Reads the Switch input data. Player count specifies how many players to read the data from, and data byte count specifies how many data bytes are to be read. The total number of bytes in the request is (players × bytes) + 1. Each bit is set to 1 when ON, 0 when OFF. 0 is returned for a non-existent switch.

Table 10: Switch Input Data Format
| bit7 | bit6 | bit5 | bit4 | bit3 | bit2 | bit1 | bit0
byte0 | TEST | TILT1 | TILT2 | TILT3 | Unused
byte1 | 1P start | 1P service | 1P up | 1P down | 1P left | 1P right | 1P push1 | 1P push2
byte2 | 1P push3 | 1P push4 | 1P push5 | 1P push6 | 1P push7 | 1P push8 | – | –
byteN | 2P start | 2P service | 2P up | 2P down | 2P left | 2P right | 2P push1 | 2P push2
byteN+1 | 2P push3 | 2P push4 | 2P push5 | 2P push6 | 2P push7 | 2P push8 | – | –

Table 11: Switch Input Data Format (2 Joysticks)
| bit7 | bit6 | bit5 | bit4 | bit3 | bit2 | bit1 | bit0
byte1 | 1P start | 1P service | 1P up | 1P/L down | 1P/L left | 1P/L right | 1P/R up | 1P/R down
byte2 | 1P/R left | 1P/R right | 1P push1 | 1P push2 | 1P push3 | 1P push4 | – | –

# DRAFT

Table 12: Switch Input Data Format (Mahjong Panel)
| bit7 | bit6 | bit5 | bit4 | bit3 | bit2 | bit1 | bit0
byte1 | start | service | A | B | C | D | E | F
byte2 | G | H | I | J | K | L | M | N
byte3 | Kan | Reach | Ron | Bet | Chi | Pon | Big | Small
byte4 | Take Score | Last Chance | Flip Flop | – | – | – | – | –

### 4.3.11 Command: Coin Inputs (COININP)

Command name | Request Data | Response Data
Coin Inputs | 21, slot | 01 (report), data, ...
byte0 | 21 | Command Code | (01) | Report
byte1 | (02) | Slot count | (00) | Slot 1 condition, coin count MSB
byte2 | – | | (02) | Slot 1 coin LSB
... | – | | ... | ...
byteN | – | | (00) | Last slot coin LSB

Read the number of coins remaining on the I/O board. Slot count specifies how many coin slots to read the data from. Each slot has two bytes of data. The top two bits contain the slot state, and the remaining 14 bits contain the coin count (up to 16383 coins). Prepaid card systems will also use this command. When using both coins and a card system, the slots are assigned to coins first, then card system.

Table 13: Coin Input Data Format
| bit7 | bit6 | bit5 | bit4 | bit3 | bit2 | bit1 | bit0
byte0 | Slot 1 Condition | | Slot 1 Coin MSB
byte1 | Slot 1 Coin LSB
byte2 | Slot 2 Condition | | Slot 2 Coin MSB
byte3 | Slot 2 Coin LSB

Table 14: Coin Condition Code List
Code | Description
00 | Normal
01 | Coin jam (coin switch is held)
02 | Counter disconnected
03 | Busy (such as card system processing)

# DRAFT

### 4.3.12 Command: Analog Inputs (ANLINP)

Command name | Request Data | Response Data
Analog Inputs | 22, channel | 01 (report), data, ...
byte0 | 22 | Command Code | (01) | Report
byte1 | (02) | Channel count | (00) | Channel 1 MSB
byte2 | – | | (02) | Channel 1 LSB
... | – | | ... | ...
byteN | – | | (00) | Last channel LSB

Reads analog inputs. Analog data is always returned as 16 bits, with the valid bits being moved to the top, and the remainder set to 0. In this way, main board software does not need to know the precision of the analog data.
For an analog joystick, the midpoint should be as close as possible to 0x8000 (I/O board should take care of sanitizing values).

Table 15: 10-bit Analog Input Data Format

| bit7 | bit6 | bit5 | bit4 | bit3 | bit2 | bit1 | bit0
byte0 | Channel 1 analog bits 9–2
byte1 | Channel 1 analog bits 1–0 | | 0
byte2 | Channel 2 analog bits 9–2
byte3 | Channel 2 analog bits 1–0 | | 0

### 4.3.13 Command: Rotary Inputs (ROTINP)

Command name | Request Data | Response Data
Rotary Inputs | 23, channel | 01 (report), data, ...
byte0 | 23 | Command Code | (01) | Report
byte1 | (02) | Channel count | (00) | Channel 1 MSB
byte2 | – | | (02) | Channel 1 LSB
... | – | | ... | ...
byteN | – | | (00) | Last channel LSB

Reads rotary encoder inputs, such as mouse data. The initial data is 0, and has 16 bits of data. As the encoder ticks, the accumulator is incremented or decremented. The returned data is the value of this encoder accumulator. Right and up movement is increment, left and down movement is decrement.

### 4.3.14 Command: Keycode Inputs (KEYINP)

Command name | Request Data | Response Data
Keycode Inputs | 24, channel | 01 (report), keycode
byte0 | 24 | Command Code | (01) | Report
byte1 | – | | (31) | Key code

Reads the state of a key array such as a keyboard. Data is always one byte. When code is 00, there is no data. Bit 7 is assigned to a held key such as shift, and the rest of the byte is used for scancode data.

### 4.3.15 Command: Screen Position Inputs (SCRPOSINP)

Command name | Request Data | Response Data
Screen Pos. Inputs | 25, channel | 01 (report), position(X,MSB), position(X,LSB), position(Y,MSB), position(Y,LSB)
byte0 | 25 | Command Code | (01) | Report
byte1 | (01) | Channel index | (00) | Position(X,MSB)
byte2 | – | | (00) | Position(X,LSB)
byte3 | – | | (00) | Position(Y,MSB)
byte4 | – | | (00) | Position(Y,LSB)

# DRAFT

Reads the state of a screen position input, such as a light gun or touch-panel. (0,0) is bottom left, and (0xFFFF,0xFFFF) is top right. Each channel is a single set of XY, and channel indices start at 01.

### 4.3.16 Command: Misc. Switch Inputs (MISCSWINP)

Command name | Request Data | Response Data
Misc. Switch Inputs | 26, bytes | 01 (report), data, ...
byte0 | 26 | Command Code | (01) | Report
byte1 | (02) | Data bytes | (02) | Switch data
... | – | | ... | ...
byteN | – | | (00) | Last switch data

Reads switches unrelated to player input. For the first byte, the 7th bit corresponds to SW1, 6th to SW2, etc. Second byte has 7th bit corresponding to SW9, 6th to SW10, etc.

### 4.3.17 Command: Remaining Payout (PAYCNT)

Command name | Request Data | Response Data
Remaining Payout | 2E, channel | 01 (report), status, remain(hi), remain(mid), remain(lo)
byte0 | 2E | Command Code | (01) | Report
byte1 | (01) | Channel index | (00) | Hopper status
byte2 | – | | (00) | Remaining (hi)
byte3 | – | | (00) | Remaining (mid)
byte4 | – | | (00) | Remaining (lo)

Reads the remaining number of medals in the specified hopper. The remaining count is 24 bits. Channel indices start at 01.

Table 16: Coin Condition Code List
Bit | Description
7 | Busy
6 | Medal jam
5 | Medals low
4 | Medals empty
3–0 | –

### 4.3.18 Command: Data Retransmit (RETRANSMIT)

Command name | Request Data | Response Data
Data Retransmit | 2F | Last response
byte0 | 2F | Command Code | ...

If the master detects a checksum error, it will send this command to request a retransmission of the last acknowledge. The retransmission must include the entire packet, including sync.

### 4.3.19 Command: Coin Counter Decrease (COINDEC)

Command name | Request Data | Response Data
Coin Counter Dec. | 30, slot, amount | 01 (report)
byte0 | 30 | Command Code | (01) | Report
byte1 | (02) | Slot index | –
byte2 | (00) | Amount (MSB) | –
byte3 | (00) | Amount (LSB) | –

Sent to decrement the number of coins stored. The amount to subtract is 16-bit.
For slot designation when using card system and coin slots together, see coin input command.

# DRAFT

### 4.3.20 Command: Payout Counter Increase (PAYINC)

Command name | Request Data | Response Data
Payout Counter Inc. | 31, slot, amount | 01 (report)
byte0 | 31 | Command Code | (01) | Report
byte1 | (02) | Slot index | –
byte2 | (00) | Amount (MSB) | –
byte3 | (00) | Amount (LSB) | –

Sent to increase the payout counter. The amount to add is 16-bit.

### 4.3.21 Command: Generic Output 1 (OUTPUT1)

Command name | Request Data | Response Data
Generic Output 1 | 32, bytes, data, ... | 01 (report)
byte0 | 32 | Command Code | (01) | Report
byte1 | (02) | Byte count | –
byte2 | (18) | First byte | –
... | ... | ... | –
byteN | (4A) | Last byte | –

Output data in a set to the generic output drivers. Each bit in each byte corresponds to a single output, with bit 7 of the first byte being the first output. Assuming the output is open collector or drain, when logic is 1, current is drained (output voltage 0V).

### 4.3.22 Command: Generic Output 2 (OUTPUT2)

Command name | Request Data | Response Data
Generic Output 2 | 37, index, data | 01 (report)
byte0 | 37 | Command Code | (01) | Report
byte1 | (03) | Byte index | –
byte2 | (18) | Output data | –

Output one byte of data to the generic output drivers. Each bit in corresponds to a single output, with bit 7 of being the first output. The byte index allows addressing 8 outputs at a time, where 01 is the first set of 8 outputs.

### 4.3.23 Command: Generic Output 3 (OUTPUT3)

Command name | Request Data | Response Data
Generic Output 3 | 38, index, data | 01 (report)
byte0 | 38 | Command Code | (01) | Report
byte1 | (03) | Bit index | –
byte2 | (00) | Output data | –

Outputs one bit to the generic output drivers. If the output data is 00 or 01, that value is output; if the data is 02, the output value is inverted.

# DRAFT

### 4.3.24 Command: Analog Output (ANLOUT)

Command name | Request Data | Response Data
Analog Outputs | 33, channel, data, ... | 01 (report)
byte0 | 33 | Command Code | (01) | Report
byte1 | (02) | Channel count | –
byte2 | (18) | Channel 1 MSB | –
byte3 | (01) | Channel 1 LSB | –
... | ... | ... | –
byteN | (4A) | Last Channel LSB | –

Outputs data to analog outputs. Analog data is always specified as 16 bits, with the valid bits being moved to the top, and the remainder set to 0. In this way, main board software does not need to know the precision of the analog data.

Table 17: 10-bit Analog Output Data Format

| bit7 | bit6 | bit5 | bit4 | bit3 | bit2 | bit1 | bit0
byte0 | Channel 1 analog bits 9–2
byte1 | Channel 1 analog bits 1–0 | | 0
byte2 | Channel 2 analog bits 9–2
byte3 | Channel 2 analog bits 1–0 | | 0

### 4.3.25 Command: Character Output (CHAROUT)

Command name | Request Data | Response Data
Analog Outputs | 34, count, data, ... | 01 (report)
byte0 | 34 | Command Code | (01) | Report
byte1 | (03) | Character count | –
byte2 | (41) | First character | –
... | ... | ... | –
byteN | (4A) | Last character | –

Outputs text to the character output. Text is encoded in ASCII, for kanji use SHIFT-JIS. The following control codes are supported.

Table 18: Character Output Control Codes
Name | Mnemonic | Code | Description
Carriage Return | CR | 0D | Return display position to beginning of line
Line Feed | LF | 0A | One row line feed
Form Feed | FF | 0C | Page break (full erase)
Backspace | BS | 08 | Backspace one character

### 4.3.26 Command: Coin Counter Increase (COININC)

Command name | Request Data | Response Data
Coin Counter Inc. | 35, slot, amount | 01 (report)
byte0 | 35 | Command Code | (01) | Report
byte1 | (02) | Slot index | –
byte2 | (00) | Amount (MSB) | –
byte3 | (00) | Amount (LSB) | –

Sent to increase the number of coins stored. The amount to add is 16-bit.
For slot designation when using card system and coin slots together, see coin input command.

# DRAFT

### 4.3.27 Command: Payout Counter Decrease (PAYDEC)

Command name | Request Data | Response Data
Payout Counter Dec. | 36, slot, amount | 01 (report)
byte0 | 36 | Command Code | (01) | Report
byte1 | (02) | Slot index | –
byte2 | (00) | Amount (MSB) | –
byte3 | (00) | Amount (LSB) | –

Sent to decrease the payout counter. The amount to subtract is 16-bit.

### 4.3.28 Command: Taito TypeX Machine Reset (TTXRESET)

Command name | Request Data | Response Data
Machine Reset | 00 | 01 (report)
byte0 | 00 | Command Code | (01) | Report

Resets the Taito TypeX machine.

### 4.3.29 Command: Taito TypeX DIP Switches (TTXDIP)

Command name | Request Data | Response Data
DIP Switches | 01, ?? | 01 (report), ??
byte0 | 01 | Command Code | (01) | Report
byte1 | (01) | ?? Always 1? | (01) | DIP Switches

Gets the DIP switch state from the TTX I/O board.

### 4.3.30 Command: Taito TypeX Unk02 (TTXUNK2)

Command name | Request Data | Response Data
Unknown 02 | 02, ? | 01 (report), ??
byte0 | 02 | Command Code | (01) | Report
byte1 | ?? | ?? | (52) | Always 52?
byte2 | ?? | ?? | –

Unknown.

### 4.3.31 Command: Taito TypeX Unk03 (TTXUNK3)

Command name | Request Data | Response Data
Unknown 03 | 03, ? | 01 (report)
byte0 | 03 | Command Code | (01) | Report
byte1 | ?? | ?? | –
byte2 | ?? | ?? | –

Unknown.

### 4.3.32 Command: Taito TypeX Watchdog? 04 (TTXWDT4)

Command name | Request Data | Response Data
Watchdog? 04 | 04 | 01 (report)
byte0 | 04 | Command Code | (01) | Report

Unknown.

# DRAFT

### 4.3.33 Command: Taito TypeX Watchdog Set (TTXWDTSET)

Command name | Request Data | Response Data
Watchdog Set | 05, time | 01 (report)
byte0 | 05 | Command Code | (01) | Report
byte1 | (0B) | Period (MSB) | –
byte2 | (B8) | Period (LSB) | –

Sets the watchdog timer period. Period is in 100ths of a second.

### 4.3.34 Command: Taito TypeX Unk06 (TTXUNK6)

Command name | Request Data | Response Data
Unknown 06 | 06, ? | 01 (report), ??
byte0 | 06 | Command Code | (01) | Report
byte1 | ?? | ?? | ?? | ??
byte2 | ?? | ?? | –

Unknown.

### 4.3.35 Command: Taito TypeX Unk07 (TTXUNK7)

Command name | Request Data | Response Data
Unknown 07 | 07, ? | 01 (report)
byte0 | 07 | Command Code | (01) | Report
byte1 | ?? | ?? | –
byte2 | ?? | ?? | –

Unknown.

### 4.3.36 Command: Taito TypeX Watchdog Kick (TTXWDTKICK)

Command name | Request Data | Response Data
Watchdog Kick | 08 | 01 (report)
byte0 | 08 | Command Code | (01) | Report
byte1 | – | | (??) | ?

TypeX Watchdog kick

### 4.3.37 Command: NAMCO Extended NOP (NAMCOEXTNOP)

Command name | Request Data | Response Data
NAMCOEXTNOP | 70, cmd | 01 (report)
byte0 | 70 | Command Code | (01) | Report
byte1 | (00) | Command Code | –

No-operation. Most unimplemented NAMCO extended command codes act as this.

### 4.3.38 Command: NAMCO Extended Read (NAMCOEXTREAD)

Command name | Request Data | Response Data
NAMCOEXTREAD | 70, 01, address | 01 (report), data
byte0 | 70 | Command Code | (01) | Report
byte1 | 01 | Command Code | (00) | Data byte 1
byte2 | (C0) | Address MSB | (00) | Data byte 2
byte3 | (20) | Address LSB | (00) | Data byte 3
... | – | | ... | ...
byte8 | – | | (00) | Data byte 8

Reads 8 bytes out of the I/O unit’s memory.

# DRAFT

### 4.3.39 Command: NAMCO Extended ID? (NAMCOEXTID)

Command name | Request Data | Response Data
NAMCOEXTID | 70, 02 | 01 (report), data
byte0 | 70 | Command Code | (01) | Report
byte1 | 02 | Command Code | (19) | Data byte 1
byte2 | – | | (97) | Data byte 2
byte3 | – | | (03) | Data byte 3
byte4 | – | | (05) | Data byte 4
byte5 | – | | (03) | Data byte 5
byte6 | – | | (19) | Data byte 6
byte7 | – | | (35) | Data byte 7
byte8 | – | | (29) | Data byte 8

Reads 8 bytes of fixed memory out of the I/O unit. Data read depends on the I/O unit?

### 4.3.40 Command: NAMCO Extended Cmd 03h (NAMCOEXT03)

Command name | Request Data | Response Data
NAMCOEXT03 | 70, 03 | 01 (report), data
byte0 | 70 | Command Code | (01) | Report
byte1 | 03 | Command Code | (19) | Data byte

Reads byte from I/O unit memory 0xC00F. (what does this do?)

### 4.3.41 Command: NAMCO Extended Cmd 04h (NAMCOEXT04)

Command name | Request Data | Response Data
NAMCOEXT04 | 70, 04 | 01 (report), data
byte0 | 70 | Command Code | (01) | Report
byte1 | 04 | Command Code | (FF) | Data byte 1
byte2 | – | | (FF) | Data byte 2

Some devices implement this, some return FF FF.

### 4.3.42 Command: NAMCO Extended Cmd 22h (NAMCOEXT22)

Command name | Request Data | Response Data
NAMCOEXT22 | 70, 22 | 01 (report)
byte0 | 70 | Command Code | (01) | Report
byte1 | 22 | Command Code | –
byte2 | ?? | ?? | –
byte3 | ?? | ?? | –
byte4 | ?? | ?? | –
byte5 | ?? | ?? | –
byte6 | ?? | ?? | –

CyberLead does not even read the inputs, just skips the bytes.

### 4.3.43 Command: CyberLead LED NOP (CYBERLEDNOP)

Command name | Request Data | Response Data
CYBERLEDNOP | 71, cmd | 01 (report)
byte0 | 71 | Command Code | (01) | Report
byte1 | (00) | Command Code | –

No-operation. Unimplemented commands do this.

# DRAFT

### 4.3.44 Command: CyberLead LED Set Scene (CYBERLEDSCENE)

Command name | Request Data | Response Data
CYBERLED01 | 71, 01, data | 01 (report)
byte0 | 71 | Command Code | (01) | Report
byte1 | 01 | Command Code | –
byte2 | (01) | Data byte 1 | –
... | ... | ... | –
byte9 | (01) | Data byte 8 | –

Seems to write ’scene’ information.
Writes 8 bytes to 0xC3A0-0xC3A8 in the I/O memory. This will get sent to the LED I/O unit soon after.

### 4.3.45 Command: CyberLead LED Data Check (CYBERLEDCHECK)

Command name | Request Data | Response Data
CYBERLED02 | 71, 02, data | 01 (report), info
byte0 | 71 | Command Code | (01) | Report
byte1 | 02 | Command Code | (00) | Info
byte2 | (01) | Data cookie | –
byte3 | (54) | Data byte 1 | –
... | ... | ... | –
byte10 | (20) | Data byte 8 | –

Cookie appears to always be 1. The data bytes are an identifier for the LED data. If this is the same as the currently uploaded LED data, 1 is returned through info. If they do not match, 2 is returned (always?). If 0 is returned, try the command again.
Info seems to be the currently-running cookie if one was already running? Cookie is ignored by LED unit. LED compares data bytes to cached values, and sets led02needsrefresh to 1 if they’re different.

### 4.3.46 Command: CyberLead LED Cmd 04h (CYBERLED04)

Command name | Request Data | Response Data
CYBERLED04 | 71, 04 | 01 (report)
byte0 | 71 | Command Code | (01) | Report
byte1 | 04 | Command Code | –

LED unit sets led02needsrefresh to 2.

### 4.3.47 Command: CyberLead LED Data Upload (CYBERLEDUPLOAD)

Command name | Request Data | Response Data
CYBERLED05 | 71, 05, cookie, data | 01 (report), info
byte0 | 71 | Command Code | (01) | Report
byte1 | 05 | Command Code | (00) | Info
byte2 | (02) | Data cookie? | –
byte3 | (5E) | LED data plane | –
byte4 | (5E) | LED data bank | –
byte5 | (5E) | LED data page | –
byte6 | (5E) | LED data byte 1 | –
... | ... | ... | –
byte69 | (5E) | LED data byte 64 | –
byte70 | (5E) | Data hash MSB | –
byte71 | (5E) | Data hash LSB | –

# DRAFT

Table 19: Data Bank Restrictions
Bank Number | First Usable Page
00 | 3E
01 | 28
02 | 18
03 | 00
04 | none
05 | none
06 | 00
... | 00
0F | 00

Bank must be 0F or less, and page must be 3F or less.
Hash is computed from all the data bytes except the data hash and command codes. Hash is computed with this algorithm:
hash = (cookie shl 8) or cookie for byte in data, hash = (hash + (byte shl 8)) xor byte
Info’s bit6 is set on the first upload command (always?). If info’s bit0 is set, command succeeded, otherwise retry this command.

### 4.3.48 Command: CyberLead LED Cmd 06h (CYBERLED06)

Command name | Request Data | Response Data
CYBERLED06 | 71, 06, cookie | 01 (report), info
byte0 | 71 | Command Code | (01) | Report
byte1 | 06 | Command Code | (00) | Info
byte2 | (02) | Data cookie? | –

Sent after each entire LED plane is uploaded. If info returns 1, command succeeded. If info returns 0, retry this command.
Seems very related to Cmd 02h, no idea what it does. Sends to LED unit, then sends 07h to LED unit. Cmd06 sets a variable to 67h, Cmd07 returns 00 if that variable is non-zero. Variable is checked for 67h and cleared periodically???

### 4.3.49 Command: CyberLead LED Upload End (CYBERLEDFINISH)

Command name | Request Data | Response Data
CYBERLED08 | 71, 08 | 01 (report)
byte0 | 71 | Command Code | (01) | Report
byte1 | 08 | Command Code | –

Finishes uploading LED data.
LED unit sets led02needsrefresh to 1.

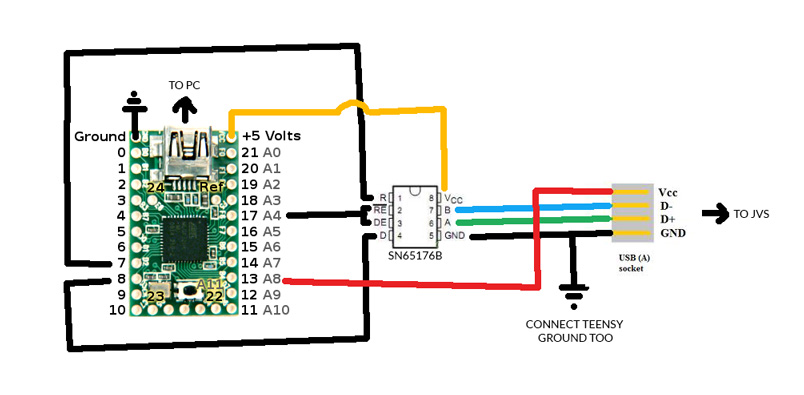
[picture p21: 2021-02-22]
images/JVSypic.jpg

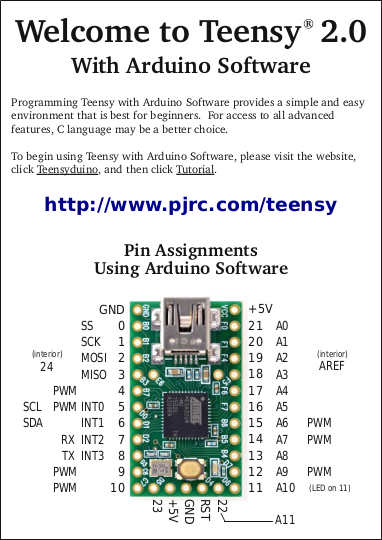
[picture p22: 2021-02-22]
images/teensy20_card2b_rev5.png

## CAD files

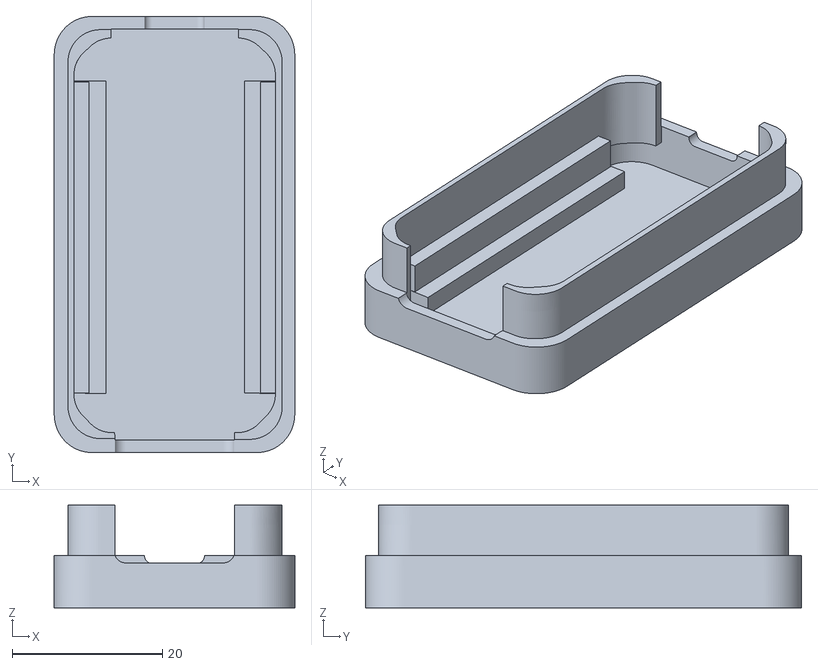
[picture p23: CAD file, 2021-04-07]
Enclosure/jvs2x bottom.stl
32.0 x 58.0 x 13.7

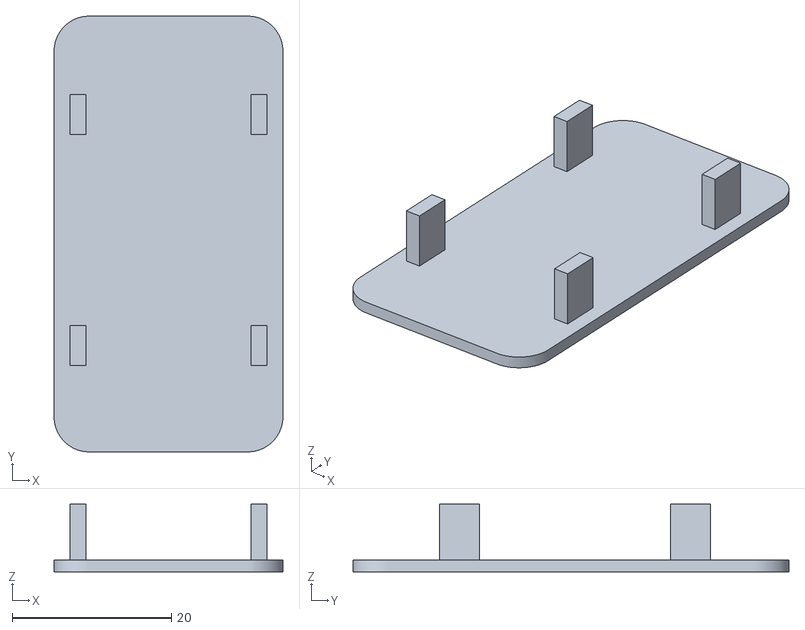
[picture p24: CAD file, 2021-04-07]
Enclosure/jvs2x shade.stl
28.7 x 54.7 x 8.50

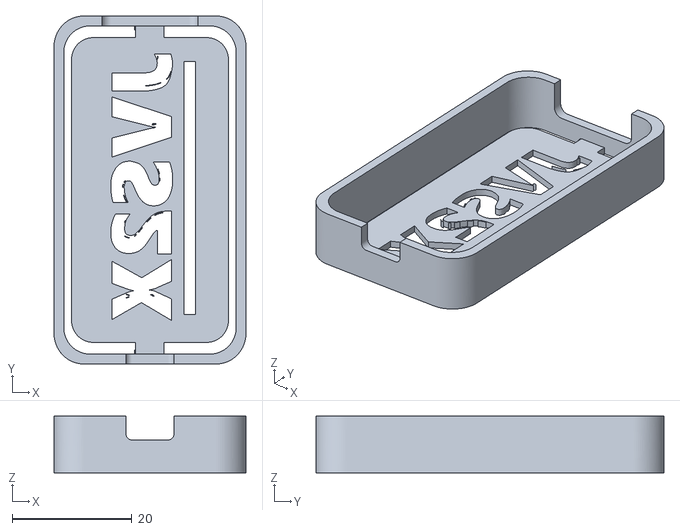
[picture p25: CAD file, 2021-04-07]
Enclosure/jvs2x top.stl
32.0 x 58.0 x 9.50

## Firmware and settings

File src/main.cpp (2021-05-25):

#include <Arduino.h>
#include "main.h"


void setup()
{
  // Start USB initialization
  usb_init();

  // INIT USB DEVICE AND INTERFANCES
	while (!usb_configured());

  // Now we can trace in Software Serial (over USB HID)
  // But wait a bit, so the host has time to detect the device and the console can read the traces
  delay(USB_START_DELAY);

  TRACE_ARGS_P( 1, "\nJVS2X %d.%d Traces\n", JVS2X_VERSION, JVS2X_REVISION);
  TRACE_P( 1, "================\n");  
  TRACE_P( 1, "USB initialization -> done\n");

  // Activate LED pin, will be used to report state
  TRACE_P( 1, "Activating LED\n");
  pinMode(11, OUTPUT);

  // Activate Hardware Serial for RS485 communication (Serial1 on Teensy 2.0)
  TRACE_P( 1, "Activating UART\n");
  blinkState(LED_START_HARDWARE_SERIAL_STATE, 25, 500, 0);
  Uart.begin(115200, DE_PIN);

  jvsHost=new JvsHost(Uart);

  TRACE_P( 1, "Set sense line to HIGH\n");
  pinMode(SENSE_PIN, OUTPUT);
  analogWrite(SENSE_PIN,1023);
}

void loop() 
{
  bool errorDetectedDuringInit;

  TRACE_P( 1, "Waiting for JVS Cable connection\n");

  // 3FF when nothing is connected
  // 345 when connected but not init
  // 029 when down
  while ((analogRead(SENSE_PIN)>900)) {blinkState(2, 500, 0, 0); }
  TRACE_P( 1, "Cable connected\n");
  
  errorDetectedDuringInit = false;

  TRACE_P( 1, "Host sends reset command\n");
  blinkState(LED_START_JVS_INIT_STATE, 25, 500, 0);
  jvsHost->resetAll();
  TRACE_P( 1, " -> done\n");

#ifndef SENSE_DISABLED
  TRACE_ARGS_P( 2, "SENSE pin before setting address(es): %d\n", analogRead(SENSE_PIN));
#else
  TRACE_P( 1, "Warning, sense detection is deactivated!\n");
#endif

  TRACE_P( 1, "Host sets address(es)\n");
  while (jvsHost->GetNextClient()) {}

  if(!jvsHost->errorTimeout && jvsHost->jvsClientCount>0) 
  {
    TRACE_ARGS_P( 1, "Total clients: %d\n", jvsHost->jvsClientCount);

    for(int cp = 0; cp < jvsHost->jvsClientCount;cp++)    
    {
      TRACE_ARGS_P( 1, "\nClient information %d\n", cp+1);
      TRACE_P( 1, "--------------------\n");
      if((errorDetectedDuringInit=!jvsHost->getBaseBoardInfo(cp)))      break;
      jvsHost->dumpBaseBoardInfo(cp);

      if((errorDetectedDuringInit=!jvsHost->getSupportedFeatures(cp)))  break;
      jvsHost->dumpSupportedFeatures(cp);

      TRACE_P( 2, "\nsetBulkCommand\n");
      jvsHost->setBulkCommand(cp);
      
      TRACE_ARGS_P( 1, "\nStarting Fuzz calculation for client: %d, nbr of channels: %d\n", 
                        cp+1, 
                        jvsHost->jvsClient[cp]->supportedFeatures.analog_input.Channels);


      jvsHost->setAnalogFuzz(cp);
      jvsHost->dumpAnalogFuzz(cp);
      
      TRACE_P( 1, " -> done\n");
    }

    if(errorDetectedDuringInit){
      TRACE_P( 1, "\nError during init phase, will restart !\n\n");
    }
    else
    {
      TRACE_P( 1, "\nJVS init success !\n\n");
      blinkState(LED_END_JVS_INIT_STATE, 25, 1000, 1);

      int nbrOfErrors=0;
      while(1)
      {
        if(analogRead(SENSE_PIN)>SENSE_DOWN) {
          TRACE_P( 2, "\nSense down detected\n");
          break; //If JVS cable is removed, the SENSE is up again
        }
        else if(jvsHost->requestReboot){
          TRACE_P( 1, "\nRequest reboot !\n\n");
                    _reboot_Teensyduino_();
        }
        else if(!jvsHost->getAllClientReports()) {
          nbrOfErrors++;
          delay(1000);

          if(nbrOfErrors==3) {
            TRACE_P( 2, "\nToo many errors getting JVS Client reports, will restart !\n\n");

            break;
          }
        }
        // HID report is done via Interrupt IN transfers:
        // - An Interrupt request is queued by the device until the host polls the USB device asking for data. (ACK + Data).
        // - If on the other hand, an interrupt condition was not present when the host polled the interrupt endpoint with an IN token, 
        //   then the function signals this state by sending a NAK.
        //
        // Maximum data payload size for full-speed devices (usb 2.0) is 64 bytes
        //
        // -> Let's try to not bombarding the consumer here... 
        else{
          nbrOfErrors=0;
          jvsHost->ForwardReportsToUSBDevice();
        }
      }
    }
  }
}

void blinkState(int nbrOfTime, int interval, int sleepAfter, int finalState)
{
  digitalWrite(11,0);
  for(int cp=0; cp<nbrOfTime;cp++)
  {
    delay(interval);
    digitalWrite(11,1);
    delay(interval);
    digitalWrite(11,0);
  }

  digitalWrite(11,finalState);
  delay(sleepAfter);
}

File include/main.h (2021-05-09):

#include <Arduino.h>
#include "JVS_HOST/jvs_host.h"

// Disable USB support from standard Teensy libray
// We will use ours.
#define USB_DISABLED

// Some LEDs indicators to show JVS2X state
#define LED_START_HARDWARE_SERIAL_STATE 1
#define LED_START_JVS_INIT_STATE        2
#define LED_END_JVS_INIT_STATE          3

#define USB_START_DELAY 	            1500

#define JVS2X_VERSION                   1
#define JVS2X_REVISION                  1

HardwareSerial Uart = HardwareSerial();
JvsHost* jvsHost;

void blinkState(int nbrOfTime, int interval, int sleepAfter, int finalState);

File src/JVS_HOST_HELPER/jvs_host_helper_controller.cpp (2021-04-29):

#ifdef JVS2PS3
#include <Arduino.h>
#include "JVS_HOST_HELPER/jvs_host_helper_controller.h"
#include "JVS_HOST_HELPER/jvs_controller_config.h"
#include "JVS_HOST/jvs_host_config.h"
#include "JVS_UART/jvs_uart.h"

#define BETWEEN(value, min, max) (value < max && value > min)

JvsHostHelperController::JvsHostHelperController(HardwareSerial& serial): 
    JvsHostHelperBase(serial) { }

bool JvsHostHelperController::parseLightgunInputChannel(JvsClient* client) 
{
    if (client->supportedFeaturesMask & FEATURE_HAS_LIGHTGUN)
    {
        /* Report Code for command SCRPOSINP */
        UART_READ_UNESCAPED();
        if(checkReportCode(incomingByte)!=REPORT_CODE_NORMAL)
            return false;

        // For now, map all supported analog channels based on nbr of players
        // not sure it's the best...
        for(int channel=0;channel < client->supportedFeatures.screen_position_input.Channels; channel++)
        {
            UART_READ_UNESCAPED(); // MSB
            //Should do the same as for analog here
            //if(BETWEEN(incomingByte, client->analogFuzz[channel][0], client->analogFuzz[channel][1])){
                if(channel==1)       CONTROLLER_ANALOG_1  = incomingByte;
                else if(channel==2)  CONTROLLER_ANALOG_2  = incomingByte;                    
            //}
            UART_READ_UNESCAPED(); // LSB (not used here, PS3 analog precision is only 255 wide)  
        }
    }
    return true;
}

bool JvsHostHelperController::parseAnalogInput(JvsClient* client) 
{
    if (client->supportedFeaturesMask & FEATURE_HAS_ANALOG_IN)
    {
        /* Report Code for command SCRPOSINP */
        UART_READ_UNESCAPED();
        if(checkReportCode(incomingByte)!=REPORT_CODE_NORMAL)
            return false;

        // For now, map all supported analog channels based on nbr of players
        // not sure it's the best...
        for(int channel=0;channel < client->supportedFeatures.analog_input.Channels; channel++)
        {
            UART_READ_UNESCAPED(); // MSB
            if(BETWEEN(incomingByte, client->analogFuzz[channel][0], client->analogFuzz[channel][1])){
                if(channel==1)       CONTROLLER_ANALOG_1  = incomingByte; 
                else if(channel==2)  CONTROLLER_ANALOG_2  = incomingByte;                    
                else if(channel==3)  CONTROLLER_ANALOG_3  = incomingByte;                    
                else if(channel==4)  CONTROLLER_ANALOG_4  = incomingByte;                    
                else if(channel==5)  CONTROLLER_ANALOG_5  = incomingByte;                    
                else if(channel==6)  CONTROLLER_ANALOG_6  = incomingByte;                    
                else if(channel==7)  CONTROLLER_ANALOG_7  = incomingByte;                    
                else if(channel==8)  CONTROLLER_ANALOG_8  = incomingByte;                    
                else if(channel==9)  CONTROLLER_ANALOG_9  = incomingByte;                    
                else if(channel==10) CONTROLLER_ANALOG_10 = incomingByte; 
            }
            UART_READ_UNESCAPED(); // LSB (not used here, PS3 analog precision is only 255 wide)  
        }
    }
    return true;
}

bool JvsHostHelperController::parseCoinInput(JvsClient* client) 
{
    if (client->supportedFeaturesMask & FEATURE_HAS_COINS) 
    {
        /* Report Code for first command COININP */
        UART_READ_UNESCAPED();
        if(checkReportCode(incomingByte)!=REPORT_CODE_NORMAL)
            return false;

        /* 2 next bytes for player x */
        for(int cp=0;cp < client->supportedFeatures.coin_input.Slots; cp++)
        {
            if(!configGamepad[client->address-1][cp]){
                uartReadMultipleUnescaped(2);
            }
            else{
                /* Slot x status on 2 first bits (on the left) */
                UART_READ_UNESCAPED();
                
                /* Slot x coin */
                UART_READ_UNESCAPED();
                if (incomingByte > client->initialSlot1CoinValue)
                {
                    client->initialSlot1CoinValue = incomingByte;
                    if(client->initialSlot1CoinValue>0){
                        usb_controller_state_t* usb_controller=configGamepad[client->address-1][cp];
                        CONTROLLER_BUTTON_COIN=1;
                    }
                }
            }
        }
    }
    return true;
}

bool JvsHostHelperController::parseSwitchInput(JvsClient* client) 
{
    if (client->supportedFeaturesMask & FEATURE_HAS_PLAYERS)
    {
        /* Report Code for first command SWINP */
        UART_READ_UNESCAPED();
        if(checkReportCode(incomingByte)!=REPORT_CODE_NORMAL)
            return false;

        /* Tilt & Test buttons */ 
        UART_READ_UNESCAPED();

        usb_controller_state_t* usb_controller=configGamepad[client->address-1][0];
        CONTROLLER_BUTTON_TEST = (BTN_GENERAL_TEST==(incomingByte & BTN_GENERAL_TEST));

        /* 2 next bytes for player x */
        for(int cp=0;cp < client->supportedFeatures.switch_input.Players; cp++)
            parseSwitchInputPlayer(configGamepad[client->address-1][cp]);
    }
    return true;
}
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

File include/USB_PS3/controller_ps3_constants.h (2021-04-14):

#ifdef JVS2PS3
#ifndef JVSCONTROLLERPS3CONSTANTS_H__
#define JVSCONTROLLERPS3CONSTANTS_H__

uint8_t not_used=0;
#define NOT_USED                    not_used
#define PS3_START_BUTTON            usb_controller->start_btn
#define PS3_SELECT_BUTTON           usb_controller->select_btn
#define PS3_PS_BUTTON               usb_controller->ps_btn
#define PS3_SQUARE_BUTTON           usb_controller->square_btn
#define PS3_SQUARE_AXIS             usb_controller->square_axis
#define PS3_CROSS_BUTTON            usb_controller->cross_btn
#define PS3_CROSS_AXIS              usb_controller->cross_axis
#define PS3_CIRCLE_BUTTON           usb_controller->circle_btn
#define PS3_CIRCLE_AXIS             usb_controller->circle_axis
#define PS3_TRIANGLE_BUTTON         usb_controller->triangle_btn
#define PS3_TRIANGLE_AXIS           usb_controller->triangle_axis
#define PS3_L1_BUTTON               usb_controller->l1_btn
#define PS3_L1_AXIS                 usb_controller->l1_axis
#define PS3_R1_BUTTON               usb_controller->r1_btn
#define PS3_R1_AXIS                 usb_controller->r1_axis
#define PS3_L2_BUTTON               usb_controller->l2_btn
#define PS3_R2_BUTTON               usb_controller->r2_btn
#define PS3_LEFT_STICK_AXIS_X       usb_controller->left_stick_axis_x
#define PS3_LEFT_STICK_AXIS_Y       usb_controller->left_stick_axis_y
#define PS3_P1_LEFT_STICK_AXIS_X    configGamepad[client->address-1][0]->left_stick_axis_x
#define PS3_P1_LEFT_STICK_AXIS_Y    configGamepad[client->address-1][0]->left_stick_axis_y
#define PS3_P2_LEFT_STICK_AXIS_X    configGamepad[client->address-1][1]->left_stick_axis_x
#define PS3_P2_LEFT_STICK_AXIS_Y    configGamepad[client->address-1][1]->left_stick_axis_y 


#endif
#endif

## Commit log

2021-02-26 Fixes, updated traces
2021-03-02 updated trace funciton
2021-03-02 detect JVS Cable
2021-03-12 prepare multi board and config
2021-04-07 3D models
    [jvs2x bottom.stl, jvs2x shade.stl, jvs2x top.stl]
2021-04-29 Trigger Start when button up
